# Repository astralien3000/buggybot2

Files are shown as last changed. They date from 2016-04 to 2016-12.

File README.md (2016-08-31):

# Buggybot

## Introduction

This is the repository of Buggybot, a four-legged robot developped by a former student of ENSEIRB-MATMECA.
It participated to several robotic competitions : 

 - Robot-Wars (2013), a small competition that took place in Bordeaux in which legged robots had to kick out 
their competitors off a ring. [Here is the old repository of the robot](https://github.com/jraynal/eirobotwar).

 - Coupe de France de robotique 2015, the french division of Eurobot 2015.
 
 - Coupe de France de robotique 2016, the french division of Eurobot 2016.
 
## Links

 - You want to see some [videos](https://youtu.be/228d_7c7TA4?list=PLfGDwqCGEbPTLqQI4HBuo4in7PoHPaz2W) of this robot ?
 - The [website](http://xenomorphales.org) of the team developing the robot.

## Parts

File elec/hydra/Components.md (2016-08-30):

Component list for <BoardName>:
- 5\* [Resistor CMS1206 200Ω 0.25W](http://www.mouser.fr/search/ProductDetail.aspx?R=0virtualkey0virtualkeyCRCW1206200RFKEA)
- 2\* [Resistor CMS1206 1kΩ 0.25W](http://www.mouser.fr/search/ProductDetail.aspx?R=0virtualkey0virtualkeyCRCW12061K00FKEA)
- 13\* [Resistor CMS1206 10kΩ 0.25W](http://www.mouser.fr/search/ProductDetail.aspx?R=0virtualkey0virtualkeyCRCW120610K0FKEA)
- 5\* [Resistor CMS1206 18kΩ 0.25W](http://www.mouser.fr/search/ProductDetail.aspx?R=0virtualkey0virtualkeyCRCW120618K0FKEA)
- 5\* [Resistor CMS1206 100kΩ 0.25W](http://www.mouser.fr/search/ProductDetail.aspx?R=0virtualkey0virtualkeyCRCW1206100KFKEA)
- 4\* [Ceramic capacitor CMS0603 100nF 25V](http://www.mouser.fr/search/ProductDetail.aspx?R=0virtualkey0virtualkeyUMK107B7104KA-T)
- 5\* [Ceramic capacitor CMS0603 1µF 25V](http://www.mouser.fr/search/ProductDetail.aspx?R=0virtualkey0virtualkeyTMK107B7105KA-T)
- 11\* [Ceramic capacitor CMS1210 10µF 25V](http://www.mouser.fr/search/ProductDetail.aspx?R=0virtualkey0virtualkeyTMK325B7106KN-TR)
- 2\* [Leaded electrolytic capacitor 330µF 35V](http://www.mouser.fr/search/ProductDetail.aspx?R=0virtualkey0virtualkeyUVZ1V331MPD)
- 5\* [Green LED CMS1206](http://www.mouser.fr/search/ProductDetail.aspx?R=0virtualkey0virtualkeyAP3216CGCK)
- 2\* [SOT-23-3 NPN transistor](http://www.mouser.fr/search/ProductDetail.aspx?R=0virtualkey0virtualkeyMMBT2222ALT1G)
- 10\* [Fuse 6.3mm x 32mm 20A 32V fast-acting](http://www.mouser.fr/search/ProductDetail.aspx?R=0virtualkey0virtualkeyBK-AGC-20-R) (10 so you have some in advance)
- 1\* [Fuse holder 30A](http://www.mouser.fr/search/ProductDetail.aspx?R=0virtualkey0virtualkey3576)
- 6\* [Vertical male connector 2.54mm 2 pins](http://www.mouser.fr/search/ProductDetail.aspx?R=0virtualkey0virtualkey22-27-2021)
- 6\* [Vertical female connector 2.54mm 2 pins](http://www.mouser.fr/search/ProductDetail.aspx?R=0virtualkey0virtualkey22-01-2025)
- 9\* [Vertical male connector 2.54mm 3 pins](http://www.mouser.fr/search/ProductDetail.aspx?R=0virtualkey0virtualkey22-27-2031)
- 9\* [Vertical female connector 2.54mm 3 pins](http://www.mouser.fr/search/ProductDetail.aspx?R=0virtualkey0virtualkey22-01-2035)
- 3\* [Vertical male connector 2.54mm 4 pins](http://www.mouser.fr/search/ProductDetail.aspx?R=0virtualkey0virtualkey22-27-2041)
- 3\* [Vertical female connector 2.54mm 4 pins](http://www.mouser.fr/search/ProductDetail.aspx?R=0virtualkey0virtualkey22-01-2045)
- 51\* [Female connector contact](http://www.mouser.fr/search/ProductDetail.aspx?R=0virtualkey0virtualkey08-50-0114)
- 6\* [Arduino shield 2.54mm 8 pins](http://www.mouser.fr/search/ProductDetail.aspx?R=0virtualkey0virtualkeyXG8V-0831)

- 1\* [Jumper (3) pins](http://www.mouser.fr/search/ProductDetail.aspx?R=0virtualkey0virtualkey929834-01-03) & [(1) pin](http://www.mouser.fr/search/ProductDetail.aspx?R=0virtualkey0virtualkey929834-01-01)

- 1\* [XT60 connectors pack (5 pairs)](http://www.hobbyking.com/hobbyking/store/__9572__Nylon_XT60_Connectors_Male_Female_5_pairs_GENUINE.html)
- 1\* [5V 5A step-down regulator](https://www.pololu.com/product/2851)
- 1\* [Arduino Mega2560](https://store.arduino.cc/product/GBX00067)

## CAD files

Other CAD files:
meca/buggybot.blend

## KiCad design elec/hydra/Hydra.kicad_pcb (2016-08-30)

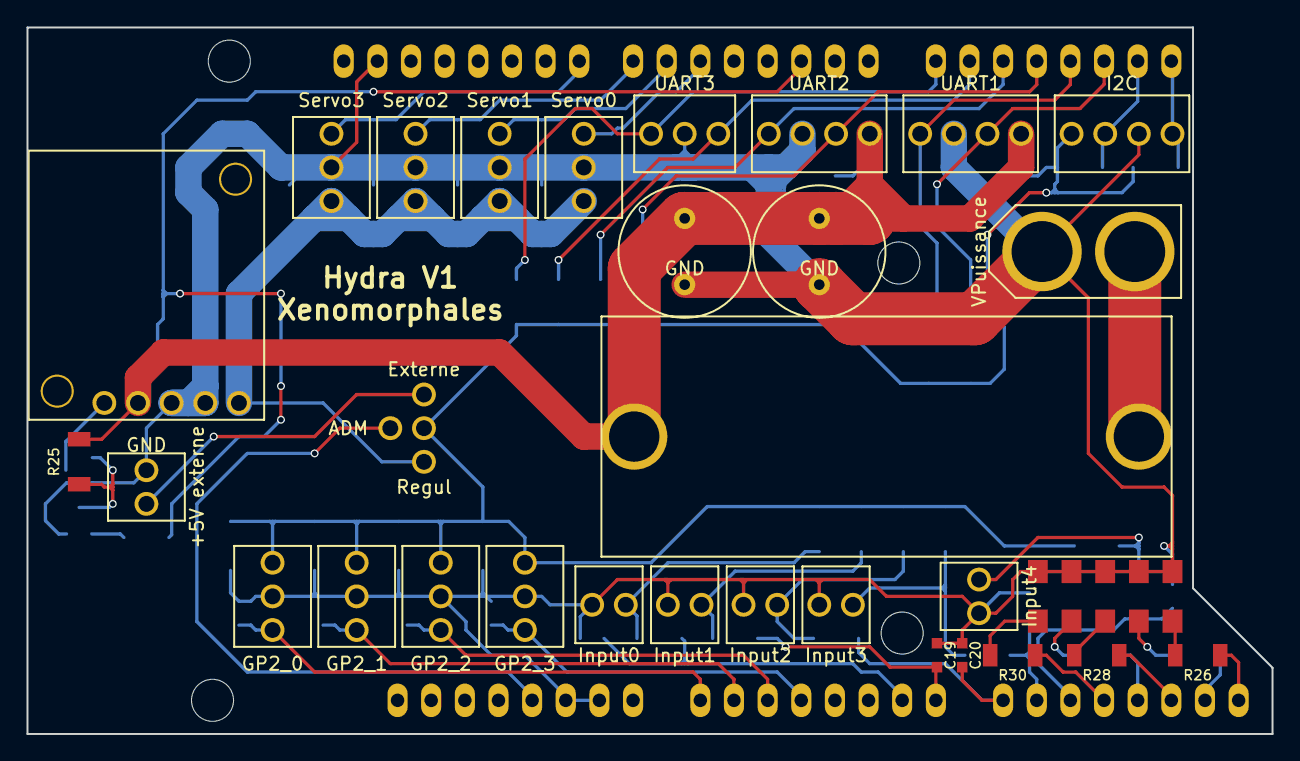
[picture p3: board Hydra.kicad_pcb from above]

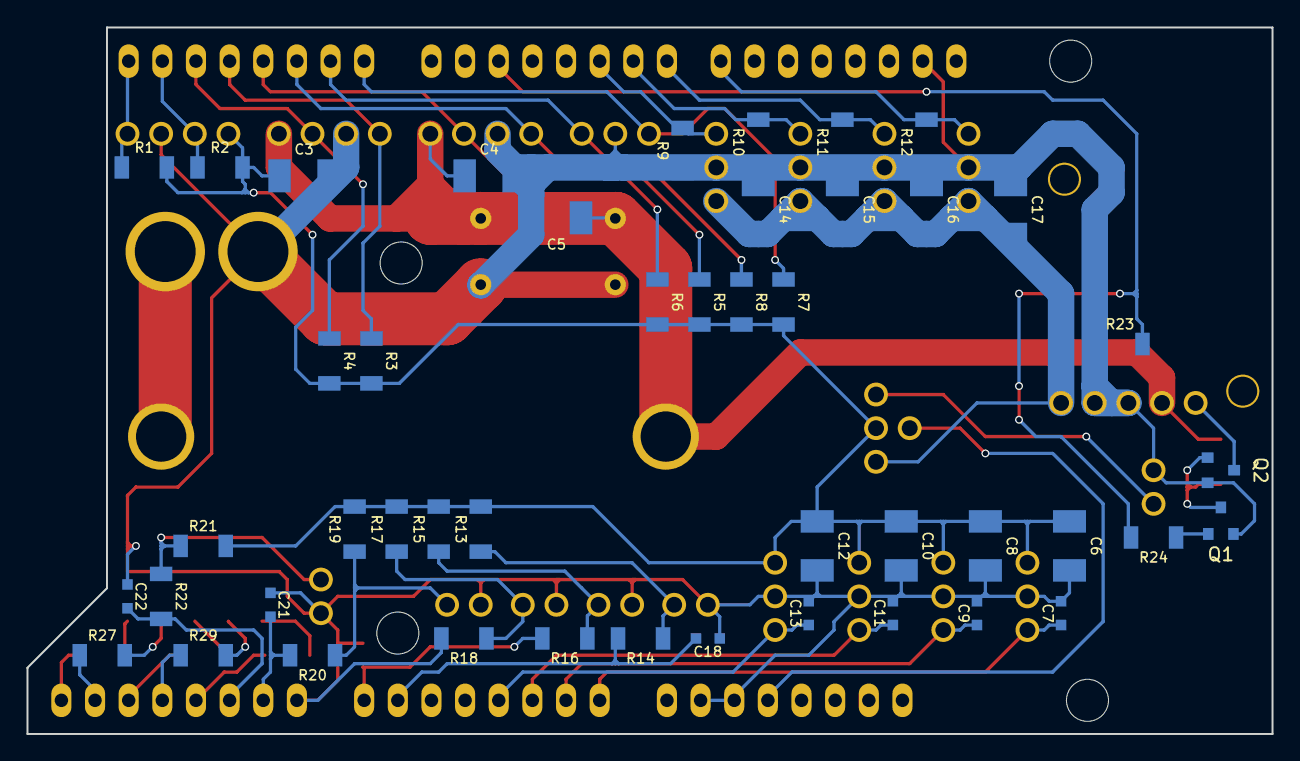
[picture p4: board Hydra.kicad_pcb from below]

Board: 2 copper layers, 94.0 x 53.3 mm, 82 parts (46 on the bottom side), 47 nets.

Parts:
+5V externe: Bat5V; Conn_01x02
C1, C2: 330µF; C_Radial
C3, C4, C5, C6, C8, C10, C12, C14, C15, C16, C17: 10µF; C_CMS1210
C7, C9, C11, C13: 100nF; C_CMS0603
C18, C19, C20, C21, C22: 1µF; C_CMS0603
D1, D2, D3, D4, D5: LED; LED_Green_CMS
F1: FUSE 20A; Fuse
GP2_0, GP2_1, GP2_2, GP2_3: GP2; Conn_01x03
I2C: I2C_1; Conn_01x04
Input0, Input1, Input2, Input3, Input4: Switch; Conn_01x02
P20: Jumper5V; 3-state_jumper
Q1, Q2: Q_NPN_BEC; SOT-23-3-bipolar-transistor
R1, R2, R3, R4, R5, R6, R7, R8, R9, R10, R11, R12, R23: 10kΩ; R_CMS1206
R13, R15, R17, R19, R21: 100kΩ; R_CMS1206
R14, R16, R18, R20, R22: 18kΩ; R_CMS1206
R24, R25: 1kΩ; R_CMS1206
R26, R27, R28, R29, R30: 200Ω; R_CMS1206
Regul1: Regul; Pololu_D24V50F5
SHIELD1: ARDUINO_MEGA_SHIELD
Servo0, Servo1, Servo2, Servo3: Servo; Conn_01x03
UART1: UART_1; Conn_01x04
UART2: UART_2; Conn_01x04
UART3: UART_3; Conn_01x03
VPuissance: Bat7.5V; Power_Conn_01x02

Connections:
/Arduino/+5VADM: P20.2, SHIELD1.5V
/Arduino/GND: +5V externe.1, C1.2, C2.2, C3.1, C4.1, C5.1, C6.1, C7.1, C8.1, C9.1, C10.1, C11.1, C12.1, C13.1, C14.2, C15.2, C16.2, C17.2, C18.2, C19.2, C20.2, C21.2, C22.2, D1.1, D2.1, D3.1, D4.1, D5.1, GP2_0.2, GP2_1.2, GP2_2.2, GP2_3.2, I2C.2, Input0.1, Input1.1, Input2.1, Input3.1, Input4.1, Q1.2, Q2.2, R9.2, R10.2, R11.2, R12.2, R23.2, Regul1.3, Regul1.4, SHIELD1.GND1, SHIELD1.GND2, SHIELD1.GND3, Servo0.2, Servo1.2, Servo2.2, Servo3.2, UART1.2, UART2.2, UART3.2, VPuissance.1
/Arduino/GP2_0: C7.2, GP2_0.1, SHIELD1.AD0
/Arduino/GP2_1: C9.2, GP2_1.1, SHIELD1.AD1
/Arduino/GP2_2: C11.2, GP2_2.1, SHIELD1.AD2
/Arduino/GP2_3: C13.2, GP2_3.1, SHIELD1.AD3
/Arduino/Input0: C18.1, R14.1, SHIELD1.AD6
/Arduino/Input1: C19.1, R16.1, SHIELD1.AD7
/Arduino/Input2: C20.1, R18.1, SHIELD1.AD8
/Arduino/Input3: C21.1, R20.1, SHIELD1.AD9
/Arduino/Input4: C22.1, R22.1, SHIELD1.AD10
/Arduino/RX1: R4.2, SHIELD1.19, UART1.3
/Arduino/RX2: R6.2, SHIELD1.17, UART2.3
/Arduino/RX3: R8.2, SHIELD1.15, UART3.3
/Arduino/RegulEnable: R23.1, R24.1, SHIELD1.2
/Arduino/SCL: I2C.1, R1.2, SHIELD1.21
/Arduino/SDA: I2C.3, R2.2, SHIELD1.20
/Arduino/TX1: R3.2, SHIELD1.18, UART1.1
/Arduino/TX2: R5.2, SHIELD1.16, UART2.1
/Arduino/TX3: R7.2, SHIELD1.14, UART3.1
/Com/+5V: C3.2, C6.2, C8.2, C10.2, C12.2, GP2_0.3, GP2_1.3, GP2_2.3, GP2_3.3, I2C.4, P20.4, R1.1, R2.1, R3.1, R4.1, R5.1, R6.1, R7.1, R8.1, R13.1, R15.1, R17.1, R19.1, R21.1
/Com/+7.5V: C1.1, C2.1, C4.2, C5.2, F1.1, R25.2, Regul1.2, UART1.4, UART2.4
/Servo1/+5V: C14.1, C15.1, C16.1, C17.1, P20.1, Regul1.5, Servo0.1, Servo1.1, Servo2.1, Servo3.1
/Servo1/PWM: R9.1, SHIELD1.5, Servo0.3
/Servo2/PWM: R10.1, SHIELD1.6, Servo1.3
/Servo3/PWM: R11.1, SHIELD1.7, Servo2.3
/Servo4/PWM: R12.1, SHIELD1.8, Servo3.3
unnamed: D1.2, R26.1
unnamed: D2.2, R27.1
unnamed: D3.2, R28.1
unnamed: D4.2, R29.1
unnamed: D5.2, R30.1
unnamed: F1.2, VPuissance.2
unnamed: Input0.2, R13.2, R14.2
unnamed: Input1.2, R15.2, R16.2
unnamed: Input2.2, R17.2, R18.2
unnamed: Input3.2, R19.2, R20.2
unnamed: Input4.2, R21.2, R22.2
unnamed: +5V externe.2, P20.3
unnamed: Q1.1, R24.2
unnamed: Q1.3, Q2.1, R25.1
unnamed: Q2.3, Regul1.1
unnamed: R26.2, SHIELD1.AD15
unnamed: R27.2, SHIELD1.AD14
unnamed: R28.2, SHIELD1.AD13
unnamed: R29.2, SHIELD1.AD12
unnamed: R30.2, SHIELD1.AD11

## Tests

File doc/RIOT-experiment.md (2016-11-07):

# RIOT and Aversive++ experiment with Buggybot

[Here is the subject of this experiment](https://youtu.be/6bN-u-e33gY). Buggybot is a four-legged robot able to walk, turn, and play various animations.

## Hardware

### Actuators

 - 12 "smart" servomotors, controlled by half-duplex UART communication
 - from 0 to 4 "basic" servomotors, when needed for a particular action

### Sensors

 - 4 Infrared distance sensors, returning an analogical signal
 - 1 gyro/accelerometer sensor, not so much used...
 - All sensors included in the smart servomotors (voltage, speed, current, force, angle)

### Control

The first hardware embedded on the robot is an Arduino Mega 2560 with a Raspberry Pi. 

 - The job of the Arduino is to handle the low-level hardware (sensors like infrared distance sensors, gyro, accelerometer or actuators like the servomotors that enable it's legs to move).
 - The Raspberry Pi will handle the Human-Robot interface (a web interface, or simple TCP communication) via Wifi, and will compute alogrithmes needed for the movement, but too time consuming for the Arduino.

## Software

### Architecture's description

The robot's software is divided in several "nodes", which are independent process that intercommunicate to provide different services. The concept of node is very similar to the ROS concept of node, even if ROS is not used in this case. Indeed, ROS is a big framework the was not supposed to support the linux distribution installed on the raspberry pi. Furthermore, since the aim was to use very few of the ROS capacity (only the message, topic, publish/subscribe systems), I chose to use a simpler library that does the job quite well : ZeroMQ.

### Presentation of the nodes

The robot has currently 8 nodes : 
 - The **embedded** node, which handle the low level hardware, and make it available to others nodes.
 - The **embedded-controller**, which just translate messages from the embedded node to others (USB/Serial to ZMQ/TCP/IP)
 - The **servo-mapper**, which will map servomotors IDs to comprehensive robot's joint (for example, a "Left Front Shoulder"), and convert angles in radians to servomotor's commands.
 - The **ik** (Inverse Kinematics) modules, which enable the robot to have an "intelligent" movement for animations. It translates positions of the feet of the robot into angles for the joints.
 - The **strategy** node, which is designed to take part to the Eurobot competition. It triggers animations to play when needed (for moving or manipulating an object, for example). This node makes the robot autonomous.
 - The **web-ui**, which is used to configure the nodes. Currently, only the servo-mapper node manage configuration.
 - The **teleoperation-server**, which replace the strategy node when the user just want to control the robot with his computer.
 - The **teleoperation-client**, which is executed on the user's device (a computer/table/smartphone), and communicate (via wifi) with the robot's teleoperation-server.

### Where does it runs ?

The first node is executed on the Arduino.
The last node may be executed anywhere, but mainly on the user's computer.
The other nodes are executed on the Raspberry Pi.

### How does the components communicate ?

The **embedded** node communicate with the **embedded-controller** via the standard USB/Serial port provided by the Arduino Mega. The protocol used is a simple custom binary protocol.

The nodes **embedded-controller**, **servo-mapper**, **ik**, **strategy**, **web-ui** and **teleoperation-server** communicate via IPC (Inter Process Communication). The library used to interface each other is ZeroMQ, which enable the nodes to use TCP instead if IPC communication with very few to no modification, so that the nodes could be executed on different platforms with no problem.

The **teleoperation-server** and **telecommunication-client** communicate via ZeroMQ/TCP (to enable wireless communication between the user and the robot).

### Which library is used for the Arduino Mega ?

No, it is not Arduino ! ;)

Aversive++ manage the Hardware abstraction layer and the different drivers (for the servomotors, mainly).

# Porting Buggybot to RIOT

The aim here is to use RIOT instead of Aversive++ as a Hardware Abstraction Layer, and use an UDP/IPv6 wireless communication instead of a custom protocol on a Serial link. This enable to remove the Raspberry from the robot and execute the code anywhere (even the cloud ?).

## Choosing a new hardware

First of all, I chose a new board that was fully compatible with RIOT, had at least 2 UART ports, and had enough memory to handle an UDP server. I chose to use the SAMR21-XPRO board, because it meets all requirements, and a very good tutorial from Alexandre Abadie was available with this board.

The biggest problem of all ARM-based boards is that GPIOs can handle 3V3 signals. Some are 5V tolerant, but it remains unsafe to use 5V signals. Anyway the SAMR21 is not 5V tolerant. So, I used a level shifter board to translate 3V3 UART to 5V UART (to communicate with the servomotors).

A second board was also needed to do the border router. As explained in the tutorial, a SAMR21-XPRO was used too.

## Porting the embedded code

Porting the embedded code, since it was only a proof of concept was quite easy. I dropped the use of sensors, which are only useful in autonomous mode, to focus on servomotors control.

Since The driver for the servomotor used in buggybot are only available for the Arduino library and the Aversive++ library, I needed to provide an adaptation layer between RIOT's UART driver and Aversive++'s Stream interface (which is used by the driver).

I followed 3 steps to have a fully functional embedded node : 
 - I made sure the servomotor driver was working with the new HAL.
 - I followed the tutorial, which sets up a COAP server. The servomotor command was done by sending a COAP PUT request with a table of 12 unsigned shots as a content. I could have stopped there, but the COAP server needed to send back an answer to the request, which increased the latency time between servomotors commands (the client had to wait for the answer).
 - I dropped the COAP server and used a simple UDP server. The UDP message are quite tiny, and don't need an answer, so that the client could send almost continuously messages. The loss of servomotor message is not a real problem for the robot, as long as it receive the last position to reach frequently enough.

## Porting other nodes

Since the embedded node is now using a well known internet standard (UDP over IPv6), the embedded-controller could be simply removed to let directly the others nodes communicate with the embedded node. But the problem of the library used for networking, ZeroMQ, is that it does not support UDP. So that, as my goal was to change as few things as possible. The embedded-controller is transformed into a ZMQ to UDP forwarder.

Others nodes were not changed at all.

## Result

[Here is the robot controlled with a SAMR21-XPRO, under RIOT](https://youtu.be/J5Ogdffptdg).

# Improvements

## Porting all nodes to RIOT

Since RIOT has the capacity to run on native target, and has capacity to establish communication between nodes, it may be interesting to port every nodes to RIOT and then unify the communication between embedded and other platforms.

## Making nodes able to run on an embedded target

Almost every nodes may be able to run on an embedded target. It would be nice to be able to move nodes from the Raspberry Pi, to the SAMR21 board, or to the cloud, or to an other embedded board that could be added to the robot. Porting the nodes to RIOT would really help to meet this aim.

## Fusioning nodes

Since nodes could run on an embedded target, it would be nice to be able to run several nodes on the same board. For example, running **embedded** and **servo-mapper** on the SAMR21 board.

## Optimisation

Especially if several nodes are running on the same embedded board, it may be interesting to not go through a complete communication stack (UDP/IPv6). The API that can switch between a full stack an a "light" stack should be transparent to the node developer.

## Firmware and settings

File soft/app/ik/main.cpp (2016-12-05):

#include <iostream>
#include <cmath>
#include <functional>

#include <cereal/types/vector.hpp>

#include <cereal/archives/json.hpp>
#include <cereal/archives/binary.hpp>

#include <zmq.hpp>

#include "robot_model.hpp"
#include "angles_converter.hpp"

#include <messages/servo_action.hpp>
#include <messages/endpoint_action.hpp>
#include <messages/optoforce_data.hpp>

#include <sys/time.h>

using namespace std;

void fwd(RobotModel& bot, AnglesConverter& ac, RobotModel::Leg leg, int id, double val) {
  ac.setAngle(leg, id, val);
  //bot.setEndpoint(leg, Matrix<double, 3,1>(50.0, 50.0, -150.0));

  cout << ac.getAngle(leg, 0) << endl;
  cout << ac.getAngle(leg, 1) << endl;
  cout << ac.getAngle(leg, 2) << endl;
  cout << endl;

  auto pos = bot.getEndpoint(leg);

  cout << pos(0,0) << endl;
  cout << pos(1,0) << endl;
  cout << pos(2,0) << endl;
}

struct ServoUpdate {
  bool updated;
  bool enabled;
  double value;
};

template<typename T>
void send(zmq::socket_t& sock_pub, T& sa) {
  stringstream oss;

  {
    cereal::BinaryOutputArchive ar(oss);
    ar(sa);
  }

  zmq::message_t msg(oss.str().size());
  oss.str().copy((char*)msg.data(), msg.size());

  sock_pub.send(msg, ZMQ_NOBLOCK);
}

void on_update_leg(zmq::socket_t& sock_pub, RobotModel& bot, AnglesConverter& ac, map<string, ServoUpdate>& up, RobotModel::Leg leg, string leg_str) {
  if(up[leg_str+"0"].updated && up[leg_str+"1"].updated && up[leg_str+"2"].updated) {
    EndpointAction ea;
    ea.label = leg_str;
    ea.enable = up[leg_str+"0"].enabled && up[leg_str+"1"].enabled && up[leg_str+"2"].enabled;

    ac.setAngle(leg, 0, up[leg_str+"0"].value);
    ac.setAngle(leg, 1, up[leg_str+"1"].value);
    ac.setAngle(leg, 2, up[leg_str+"2"].value);

    auto pos = bot.getEndpoint(leg);

    ea.x = pos(0,0);
    ea.y = pos(1,0);
    ea.z = pos(2,0);

    send(sock_pub, ea);
    up[leg_str+"0"].updated = false;
    up[leg_str+"1"].updated = false;
    up[leg_str+"2"].updated = false;
  }
}

void on_update(zmq::socket_t& sock_pub, RobotModel& bot, AnglesConverter& ac, map<string, ServoUpdate>& up) {
  on_update_leg(sock_pub, bot, ac, up, RobotModel::Leg::LF, "LF");
  on_update_leg(sock_pub, bot, ac, up, RobotModel::Leg::RF, "RF");
  on_update_leg(sock_pub, bot, ac, up, RobotModel::Leg::LB, "LB");
  on_update_leg(sock_pub, bot, ac, up, RobotModel::Leg::RB, "RB");
}

RobotModel::Leg lbl2leg(string lbl) {
  if(lbl == "LF") {
    return RobotModel::Leg::LF;
  }
  else if(lbl == "RF") {
    return RobotModel::Leg::RF;
  }
  else if(lbl == "LB") {
    return RobotModel::Leg::LB;
  }
  else if(lbl == "RB") {
    return RobotModel::Leg::RB;
  }
  return RobotModel::Leg::NONE;
}

void config_sock(zmq::socket_t& sock) {
  int hwm = 1;
  int linger = 0;
  sock.setsockopt(ZMQ_SNDHWM, &hwm, sizeof(hwm));
  sock.setsockopt(ZMQ_RCVHWM, &hwm, sizeof(hwm));
  sock.setsockopt(ZMQ_LINGER, &linger, sizeof(linger));
}

int main(int, char**) {
  // Update config
  map<string, ServoUpdate> servo_update;

  // Model config
  RobotModel bot(0.003, 100, 1);
  AnglesConverter ac(bot);

  ac.setAngleConvertion(RobotModel::Leg::LF, 2, 0, -1);

  ac.setAngleConvertion(RobotModel::Leg::RF, 0, 0, -1);
  ac.setAngleConvertion(RobotModel::Leg::RF, 1, 0, -1);
  ac.setAngleConvertion(RobotModel::Leg::RF, 2, 0, -1);

  ac.setAngleConvertion(RobotModel::Leg::LB, 0, 0, -1);

  ac.setAngleConvertion(RobotModel::Leg::RB, 1, 0, -1);

  ac.setAngle(RobotModel::Leg::LF, 2, 3.1415/2);
  ac.setAngle(RobotModel::Leg::RF, 2, 3.1415/2);
  ac.setAngle(RobotModel::Leg::LB, 2, 3.1415/2);
  ac.setAngle(RobotModel::Leg::RB, 2, 3.1415/2);

  // IO config
  zmq::context_t ctx(6);

  zmq::socket_t sock_servo_in(ctx, ZMQ_SUB);
  sock_servo_in.connect("ipc://servo.in");
  sock_servo_in.bind("ipc://debug.servo.in");
  sock_servo_in.setsockopt(ZMQ_SUBSCRIBE, 0, 0);

  zmq::socket_t sock_servo_out(ctx, ZMQ_PUB);
  sock_servo_out.connect("ipc://servo.out");
  sock_servo_out.bind("ipc://debug.servo.out");

  zmq::socket_t sock_ik_in(ctx, ZMQ_PUB);
  sock_ik_in.bind("ipc://ik.in");

  zmq::socket_t sock_ik_out(ctx, ZMQ_SUB);
  sock_ik_out.bind("ipc://ik.out");
  sock_ik_out.setsockopt(ZMQ_SUBSCRIBE, 0, 0);

  config_sock(sock_ik_in);
  config_sock(sock_ik_out);
  config_sock(sock_servo_in);
  config_sock(sock_servo_out);

  struct timeval t1 = {0,0}, t2 = {0,0};

  while(1) {
    gettimeofday(&t2, NULL);
    if(abs(t2.tv_usec - t1.tv_usec) > 30000) {
      on_update(sock_ik_in, bot, ac, servo_update);
      t1.tv_sec = t2.tv_sec;
      t1.tv_usec = t2.tv_usec;
    }

    try {
      zmq::message_t msg;
      if(sock_servo_in.recv(&msg, ZMQ_NOBLOCK)) {
	//cout << "SERVO_IN" << endl;
	std::stringstream ss;
	ss.write((char*)msg.data(), msg.size());
	cereal::BinaryInputArchive ar(ss);
	ServoAction action;
	ar(action);

	ServoUpdate& up = servo_update[action.label];
	up.updated = true;
	up.value = action.angle;
	up.enabled = action.enable;
      }
    }
    catch(zmq::error_t e) {
      cout << "zmq::error : " << e.what() << endl;
    }
    catch(cereal::RapidJSONException e) {
      cout << "cereal::error : " << e.what() << endl;
    }

    {
      zmq::message_t msg;
      if(sock_ik_out.recv(&msg, ZMQ_NOBLOCK)) {
	//cout << "IK_OUT" << endl;
	std::stringstream ss;
	ss.write((char*)msg.data(), msg.size());
	cereal::BinaryInputArchive ar(ss);

	vector<ServoAction> sas;

	vector<EndpointAction> eas;
	ar(eas);

	//cout << "test \t" << t1.tv_usec << endl;
	for(auto it = eas.begin() ; it != eas.end() ; it++) {

	  EndpointAction& ea = *it;
	  //ar(ea);

	  Matrix<double, 3,1> pos(ea.x, ea.y, ea.z);
	  bot.setEndpoint(lbl2leg(ea.label), pos);
	  //cout << "test \t" << t2.tv_usec << "\t" << ea.label << endl;

	  ServoAction sa;

	  sa.label = ea.label+"0";
	  sa.enable = ea.enable;
	  sa.angle = ac.getAngle(lbl2leg(ea.label), 0);
	  //send(sock_servo_out, sa);
	  sas.push_back(sa);

	  sa.label = ea.label+"1";
	  sa.enable = ea.enable;
	  sa.angle = ac.getAngle(lbl2leg(ea.label), 1);
	  //send(sock_servo_out, sa);
	  sas.push_back(sa);

	  sa.label = ea.label+"2";
	  sa.enable = ea.enable;
	  sa.angle = ac.getAngle(lbl2leg(ea.label), 2);
	  //send(sock_servo_out, sa);
	  sas.push_back(sa);

	}
	//cout << sas.size() << endl;
	send(sock_servo_out, sas);
      }
    }

  }

  return 0;
}

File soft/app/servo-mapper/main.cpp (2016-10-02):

#include <messages/servo_action.hpp>
#include <messages/servo_config.hpp>

#include <iostream>
#include <cmath>
#include <functional>
#include <map>
#include <fstream>

#include <unistd.h>

#include <zmq.hpp>


#include <cereal/types/map.hpp>
#include <cereal/types/vector.hpp>
#include <cereal/types/string.hpp>

#include <cereal/archives/json.hpp>
#include <cereal/archives/binary.hpp>

using namespace std;

template<typename T>
void send(zmq::socket_t& sock_pub, T& sa) {
  stringstream oss;

  {
    cereal::BinaryOutputArchive ar(oss);
    ar(sa);
  }

  zmq::message_t msg(oss.str().size());
  oss.str().copy((char*)msg.data(), msg.size());

  sock_pub.send(msg, ZMQ_NOBLOCK);
}

template<typename T>
void send_json(zmq::socket_t& sock_pub, T& sa) {
  stringstream oss;

  {
    cereal::JSONOutputArchive ar(oss);
    ar(sa);
  }

  zmq::message_t msg(oss.str().size());
  oss.str().copy((char*)msg.data(), msg.size());

  sock_pub.send(msg, ZMQ_NOBLOCK);
}

void config_sock(zmq::socket_t& sock) {
  int hwm = 1;
  int linger = 0;
  sock.setsockopt(ZMQ_SNDHWM, &hwm, sizeof(hwm));
  sock.setsockopt(ZMQ_RCVHWM, &hwm, sizeof(hwm));
  sock.setsockopt(ZMQ_LINGER, &linger, sizeof(linger));
}

void sync_map_id(map<uint8_t, ServoConfig>& configs) {
  for(auto it = configs.begin() ; it != configs.end() ; it++) {
      if(it->first != it->second.id) {
          it->second.id = it->first;
          cout << "invalid id -> changing" << endl;
        }
    }
}

void load_configs(map<uint8_t, ServoConfig>& configs) {
  configs.clear();

  try {
    ifstream ifs("servo-mapper.json", ios_base::in);

    cereal::JSONInputArchive ar(ifs);
    ar(CEREAL_NVP(configs));
    sync_map_id(configs);
  }
  catch(cereal::RapidJSONException e) {
    cout << "load : " << e.what() << endl;
  }
  catch(cereal::Exception e) {
    cout << "load : " << e.what() << endl;
  }
}

void save_configs(map<uint8_t, ServoConfig>& configs) {
  sync_map_id(configs);
  ofstream ofs("servo-mapper.json", ios_base::out);
  cereal::JSONOutputArchive ofar(ofs);
  ofar(CEREAL_NVP(configs));
}

template<typename T>
void answer(zmq::socket_t& sock_config, string action, T data) {
  stringstream oss;

  {
    cereal::JSONOutputArchive ar(oss);
    ar(CEREAL_NVP(action), CEREAL_NVP(data));
  }

  zmq::message_t msg(oss.str().size());
  oss.str().copy((char*)msg.data(), msg.size());

  sock_config.send(msg, ZMQ_NOBLOCK);
}

uint8_t find_config_by_label(map<uint8_t, ServoConfig>& configs, string label) {
  for(auto it = configs.begin() ; it != configs.end() ; it++) {
      if(it->second.label == label) {
          return it->first;
        }
    }
  return 0xFF;
}

int main(int argc, char* argv[]) {
  zmq::context_t ctx(5);
  map<uint8_t, ServoConfig> configs;

  load_configs(configs);
  if(configs.empty()) cout << "empty" << endl;

  zmq::socket_t sock_embed_in(ctx, ZMQ_SUB);
  sock_embed_in.connect("ipc://embed.in");
  sock_embed_in.setsockopt(ZMQ_SUBSCRIBE, 0, 0);

  zmq::socket_t sock_embed_out(ctx, ZMQ_PUB);
  sock_embed_out.connect("ipc://embed.out");

  zmq::socket_t sock_servo_in(ctx, ZMQ_PUB);
  sock_servo_in.bind("ipc://servo.in");

  zmq::socket_t sock_servo_out(ctx, ZMQ_SUB);
  sock_servo_out.bind("ipc://servo.out");
  sock_servo_out.setsockopt(ZMQ_SUBSCRIBE, 0, 0);

  zmq::socket_t sock_config(ctx, ZMQ_REP);
  sock_config.bind("ipc://servo-mapper.config");

  zmq::socket_t sock_servo_json_in(ctx, ZMQ_PUB);
  sock_servo_json_in.bind("ipc://servo.json.in");

  zmq::socket_t sock_embed_json_in(ctx, ZMQ_PUB);
  sock_embed_json_in.bind("ipc://embed.json.in");

  config_sock(sock_embed_in);
  config_sock(sock_embed_out);
  config_sock(sock_servo_in);
  config_sock(sock_servo_out);

  while(1) {

      try {
        zmq::message_t msg;
        if(sock_config.recv(&msg, ZMQ_NOBLOCK)) {
            std::stringstream ss;
            ss.write((char*)msg.data(), msg.size());
            cereal::JSONInputArchive ar(ss);

            string action;
            ar(CEREAL_NVP(action));

            if(action == string("getall")) {
                cout << "config : getall" << endl;

                answer(sock_config, action, configs);
              }
            else if(action == string("get")) {
                cout << "config : get" << endl;

                uint16_t id = 0;
                ar(CEREAL_NVP(id));

                if(configs.count(id)) {
                    answer(sock_config, action, configs[id]);
                  }
                else {
                    answer(sock_config, string("error"), string("none"));
                  }
              }
            else if(action == string("set")) {
                cout << "config : set" << endl;

                ServoConfig config;
                ar(CEREAL_NVP(config));
                configs[config.id] = config;

                answer(sock_config, action, string("ok"));
                save_configs(configs);
              }
            else {
                answer(sock_config, string("error"), string(""));
              }
          }
      }
      catch(zmq::error_t e) {
        cout << "config error : " << e.what() << endl;
        answer(sock_config, string("error"), string(e.what()));
      }
      catch(cereal::RapidJSONException e) {
        cout << "config error : " << e.what() << endl;
        answer(sock_config, string("error"), string(e.what()));
      }

      {
        zmq::message_t msg;
        if(sock_embed_in.recv(&msg, ZMQ_NOBLOCK)) {
            std::stringstream ss;
            ss.write((char*)msg.data(), msg.size());

            HardwareServoAction hsa;

            {
              cereal::BinaryInputArchive ar(ss);
              ar(hsa);
            }

            if(!configs.count(hsa.id)) {
                configs[hsa.id] = ServoConfig();
                configs[hsa.id].id = hsa.id;
              }

	    send_json(sock_embed_json_in, hsa);

            try {
              ServoConfig& config = configs[hsa.id];
              stringstream oss;

              ServoAction action;
              action.label = config.label;
              action.enable = false;
              action.angle = config.pos2angle(hsa.position);

              {
                cereal::BinaryOutputArchive ar(oss);
                ar(action);
              }

              zmq::message_t msg(oss.str().size());
              oss.str().copy((char*)msg.data(), msg.size());

              sock_servo_in.send(msg, ZMQ_NOBLOCK);

              send_json(sock_servo_json_in, action);
            }
            catch(const char* msg) {
	      //cout << "ERROR : " << msg << endl;
            }
          }
      }

      {
        zmq::message_t msg;
        if(sock_servo_out.recv(&msg, ZMQ_NOBLOCK)) {
            std::stringstream ss;
            ss.write((char*)msg.data(), msg.size());

            vector<HardwareServoAction> hsas;
            vector<ServoAction> sas;

            {
              cereal::BinaryInputArchive ar(ss);
              ar(sas);
            }
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

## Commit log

2014-11-01 Added servo_config
2014-11-01 Separation of servo_tester
2014-11-02 Created a shell for calibration
2014-11-16 Changed compile chain to cmake
2014-11-24 Mesh generation script.
    [simu.blend]
2014-11-25 Added MGI and MGD to blender simulation
    [simu.blend]
2014-11-28 simu MGD and MGI
    [simu.blend]
2014-11-28 Communicaton between robot and computer works ! The robot can "walk". Servo are calibrated
    [simu.blend]
2015-02-27 Begin to designe arduino shield.
    [adm_shield.sch, i2c.sch, servo.sch]
2015-02-27 Modified servos (120Hz -> 60Hz)
2015-02-27 Continuation of Kicad schematics.
    [adm_shield.sch, alim.sch, arduino.sch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]
2015-02-28 Schematics finished ?
    [adm_shield.sch, alim.sch, arduino.sch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]
2015-02-28 Begining of the PCB.
    [adm_shield.kicad_pcb, adm_shield.sch, alim.sch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]
2015-02-28 PCB almost finished ?
    [adm_shield.kicad_pcb, arduino.sch, i2c.sch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]
2015-02-28 First version PCB.
    [adm_shield.kicad_pcb, arduino.sch]
2015-03-01 Shield V2 (PCB begining)
    [adm_shield.kicad_pcb, adm_shield.sch, alim.sch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]
2015-03-01 Before routing.
    [adm_shield.kicad_pcb]
2015-03-01 PCB almost finished !
    [adm_shield.kicad_pcb]
2015-03-01 PCB FINISHED ! + Correction of schematics.
    [adm_shield.kicad_pcb, arduino.sch, leg.sch]
2015-03-01 Modified ServoTester init. Modified Servos pin mapping. Added a security to SetAngle (0 div).
2015-03-02 PCB v3 !
    [adm_shield.kicad_pcb]
2015-03-02 V3.1 ?
    [adm_shield.kicad_pcb, adm_shield.sch, alim.sch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]
2015-03-06 New wlaking algo. PCB v4
    [adm_shield.kicad_pcb]
2015-03-06 PCB v4.1
    [adm_shield.kicad_pcb]
2015-03-14 Awesome new control program is working !!!
    [buggybot2.blend]
2015-03-15 Better connection management
    [buggybot2.blend]
2015-03-18 Turn and climb animations
    [buggybot2_climb.blend, buggybot2_turn.blend]
2015-04-06 Added accelero test.
    [buggybot2.blend]
2015-04-12 Test comm with arduino
2015-04-27 Added adc module.
2015-04-27 Moved soft directories
    [buggybot2.blend, buggybot2_climb.blend, buggybot2_turn.blend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]
2015-04-27 Moved files in soft/embed (WARNING -> doesn't compile)
    [arduino.cpp, main.cpp, test.cpp]
2015-04-27 ADC test compiles !
2015-04-29 Updated MGD model. MGI have to be changed, but gives values near from Blender's ones.
    [buggybot2.blend]
2015-04-29 New MGI implemented in python !!!
    [buggybot2.blend]
2015-05-01 Debug MGI !
    [buggybot2.blend]
2015-05-02 Cleaned MGD code
    [buggybot2.blend]
2015-05-02 Cleaned blend file
    [buggybot2.blend]
2015-05-02 Improved animation
    [buggybot2.blend]
2015-05-02 Comm blender - robot works !
    [buggybot2.blend]
2015-05-03 Animation PASSMURAILLE
    [buggybot2.blend]
2015-05-03 Blender-independent code
    [buggybot2.blend]
2015-05-03 Added old walk anim improved
    [buggybot2_walk.blend]
2015-05-03 Added turn anim
    [buggybot2_turn.blend]
2015-05-14 NEW CRAWL ANIM !!!
    [buggybot2.blend]
2015-05-15 Begin Match
    [buggybot2.blend]
2015-05-15 New walk anim
    [buggybot2_walk.blend]
2015-05-15 Match almost done ?
    [buggybot2.blend]
2015-09-01 Calib with 31kg servo
    [buggybot2_walk.blend]
2015-09-01 Begining of new elec board
    [accelero.sch, alim_log.sch, alim_pow.sch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]
2015-09-02 Completed new board schematics.
    [GP2.sch, accelero.sch, alim_log.sch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]
2015-09-17 Added autodesk meca
    [anti_axe.ipt, arm.ipt, base.ipt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]
2015-11-07 Elec ?
    [GP2.sch, accelero.sch, alim_log.sch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]
2015-11-07 Big dirty commit
    [buggybot2_sit.blend, file55E7F03D.sch]
2015-11-08 Moved old strategy code to test dir
    [buggybot2.blend, buggybot2_climb.blend, buggybot2_sit.blend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]
2015-11-12 Begining of blender node
    [buggybot2.blend]
2015-11-26 BlenderViz implementation (not finished)
    [buggybot2.blend]
2016-03-26 Reorganized soft directory
    [buggybot2.blend, buggybot2_climb.blend, buggybot2_sit.blend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]
2016-03-28 rm all
    [buggybot2.blend]
2016-03-31 Added servo communication
2016-04-04 Merged zmq embed sockets
2016-04-04 Debug config serialization (cereal doesn't handle JSON "inf" value)
    [main.cpp]
2016-04-05 Debug servo-mapper
2016-04-05 servo-mapper fully configurable
2016-04-06 Web ui can display current angle and position. Added 'enabled' attributes to servo messages
2016-04-06 [servo-mapper] Add default id to new servo.
2016-04-09 Added buggybot blender mode with armature
    [buggybot.blend]
2016-04-09 Removed old meca
    [anti_axe.ipt, arm.ipt, base.ipt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]
2016-04-09 improved ik exporter
    [buggybot.blend]
2016-04-09 ik_export script completed
    [buggybot.blend]
2016-04-09 ik_export debug
    [buggybot.blend]
2016-04-10 Rotation of the model to make the left front leg into positive x and y coordinates.
    [buggybot.blend]
2016-04-11 Added "NONE" leg
2016-04-11 Debug of arduino random reset
    [main.cpp]
2016-04-11 All servos connected !
2016-04-13 Test with 4 legs
2016-04-18 embed-controller error handle improved
    [main.cpp]
2016-04-19 Renamed optoforce sensors
2016-04-20 Calibration of optoforce ik !
2016-04-29 Reset default servo values
    [main.cpp]
2016-05-01 Added ADC and PWM drivers
2016-05-01 Servo OK
2016-05-02 Test Regulator Enable (not working because of electronics)
    [main.cpp]
2016-05-03 gp2.in and bumper.in sockets created
2016-05-12 Debug servo-mapper config messages when no config available
2016-08-28 Various debugs + error messages.
    [main.cpp]
2016-08-30 Adding Hydra board files
    [Arduino.sch, Com.sch, GP2.sch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]
2016-08-31 Clean elec directory
    [Arduino.sch, Com.sch, GP2.sch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]
2016-09-09 Removed old arduino shield
    [adm_shield.kicad_pcb, adm_shield.sch, alim.sch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]
2017-01-23 Added alive thread
2017-02-09 toolchain-switch -> cmake-toolchain
